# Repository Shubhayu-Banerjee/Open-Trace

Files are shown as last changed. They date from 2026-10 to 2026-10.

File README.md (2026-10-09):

# OpenTrace

OpenTrace is a custom RP2040-based USB logic analyzer designed to capture digital signals from external circuits for inspection on a computer. This repository documents the hardware design completed so far.

OpenTrace v1

## What has been designed

### RP2040 core

- Selected the **Raspberry Pi RP2040** as the main MCU.
- Designed the core around an external **W25Q16JV QSPI flash** (16 Mbit / 2 MB).
- Added the 12 MHz crystal oscillator circuit, using the RP2040 reference topology as the design basis.
- Added local supply decoupling capacitors and the RP2040's 3.3 V / 1.1 V regulator-related connections.
- Tied `TESTEN` low.
- Added a `RUN` reset circuit using a 10 kΩ pull-up to +3V3 and a normally-open momentary switch to GND.

### USB-C interface

- Added a USB-C receptacle for USB 2.0 device connectivity.
- Added separate **5.1 kΩ pull-down resistors from CC1 and CC2 to GND**.
- Combined the receptacle's duplicate USB 2.0 contacts correctly: A6/B6 for D+ and A7/B7 for D−.
- Added a **USBLC6-2SC6** for USB D+/D− ESD protection.
- Added an **AMS1117-3.3** regulator stage to derive 3.3 V from USB VBUS in the current schematic.

### Eight-channel input stage

- Selected the **SN74LVC245A-family octal buffer**, with the current schematic using `SN74LVC245APW`.
- Set `DIR` low for A-to-B signal flow.
- Set active-low `/OE` low to enable the outputs.
- Added a 100 nF bypass capacitor at the buffer's supply.
- Added an eight-signal probe connector (`J2`) and wired its eight signals to buffer inputs A1–A8.
- Wired the corresponding B1–B8 outputs to RP2040 GPIOs **GPIO25 through GPIO18**, respectively:

| Probe / buffer channel | RP2040 GPIO |
|---|---:|
| Channel 1 (A1 → B1) | GPIO18 |
| Channel 2 (A2 → B2) | GPIO19 |
| Channel 3 (A3 → B3) | GPIO20 |
| Channel 4 (A4 → B4) | GPIO21 |
| Channel 5 (A5 → B5) | GPIO22 |
| Channel 6 (A6 → B6) | GPIO23 |
| Channel 7 (A7 → B7) | GPIO24 |
| Channel 8 (A8 → B8) | GPIO25 |

The mapping above records the schematic mapping discussed so far; it must still be checked against the final display/encoder pin assignments.

### Probe-input ESD decision

- Evaluated multiple eight-channel and single-/multi-line ESD protection options, including the SP4065-08ATG, TPD4E05U06, DRTR5V0U4S-7, PESD5V0U1BA, PESD5V0L1BA, NUP4114, and PESD5V0C2BDFZ.
- No probe-side ESD protector was selected as a verified solution. The main blocker was finding a part that was available, had a practical footprint, and had transient/clamping characteristics appropriately evaluated against the SN74LVC245A input limits.
- **The current design decision is to omit the dedicated probe-input ESD array for this revision**, rather than add an unverified component. This leaves the exposed probe inputs without dedicated ESD protection and is a known limitation.
- The USBLC6-2SC6 remains assigned to USB D+/D−, not to the probe inputs.

## Important current design details

| Item | Current design |
|---|---|
| Main MCU | Raspberry Pi RP2040 |
| QSPI flash | W25Q16JV, 16 Mbit / 2 MB |
| Clock | 12 MHz crystal circuit |
| USB | USB-C, USB 2.0 |
| USB ESD | USBLC6-2SC6 on D+/D− |
| USB-to-3.3 V regulator | AMS1117-3.3 candidate |
| Probe buffer | SN74LVC245APW |
| Probe inputs | 8 digital channels |
| Probe-to-GPIO mapping | GPIO25, GPIO24, GPIO23, GPIO22, GPIO21, GPIO20, GPIO19, GPIO18 |
| Probe ESD | Omitted for current revision; not protected by a dedicated ESD array |
| Reset | `RUN` with 10 kΩ pull-up and momentary switch to GND |
| Boot configuration | `TESTEN` tied low; flash/BOOTSEL arrangement needs final verification |

## Decisions and trade-offs made

- Chose **RP2040** rather than a more complex FPGA or another MCU for this revision, prioritizing a feasible custom board and PIO-based deterministic sampling.
- Kept the external QSPI flash and 12 MHz crystal as part of the bare-MCU design.
- Used a USB-C connector with the correct device-side CC pull-down approach.
- Added dedicated ESD protection to the USB data lines.
- Chose the SN74LVC245A-family device as the eight-channel input buffer.
- Deferred probe-input ESD protection because candidate parts were unavailable or could not be validated as a complete protection solution within the current design effort.
- Prioritized getting a coherent, manufacturable first PCB over adding a component whose electrical suitability was uncertain.

## Known limitations / items not yet verified

This repository describes the design work completed so far; it does not claim the PCB has been fabricated or tested.
- The probe inputs have no dedicated ESD array in the current revision. Treat them as unprotected inputs.

## References

- [RP2040 hardware design guide](https://datasheets.raspberrypi.com/rp2040/hardware_design_with_rp2040.pdf)
- [RP2040 documentation portal](https://pip.raspberrypi.com/categories/814-rp2040)
- [Texas Instruments SN74LVC245A](https://www.ti.com/product/SN74LVC245A)
- [ST USBLC6-2SC6](https://www.st.com/en/protections-and-emi-filters/usbllc6-2.html)

## License

No license has been specified yet.

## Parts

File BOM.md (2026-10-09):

# OpenTrace – bill of materials

<!-- Generated by Half Life from project cmv0laarm01us01mcl110xg83. Edits here are overwritten on the next sync. -->
<!-- Generated: 2026-10-09T13:05:42.587Z -->

> [!NOTE]
> This parts list is mirrored from [Half Life](https://halflife.hackclub.com). Editing it here will not change the platform's copy, and the next sync overwrites this file.

| Week | Tier | Parts funding |
| --- | --- | --- |
| Week 1 | Tier 1 | $30.00 |

| Part | What it's for | Qty | Unit | Total | Vendor |
| --- | --- | --- | --- | --- | --- |
| [535-ABM8-272-T3CT-ND](https://www.digikey.in/en/products/detail/abracon-llc/ABM8-272-T3/22472366) | Clock for the RP2040 | 1 | $0.69 | $0.69 | [Digikey](https://www.digikey.in/en/products/detail/abracon-llc/ABM8-272-T3/22472366) |
| [Raspberry PI RP2040 Microcontroller IC](https://robu.in/product/raspberry-pi-rp2040/) | Main controller | 1 | $0.66 | $0.66 | [Robu](https://robu.in/product/raspberry-pi-rp2040/) |
| [TPD4E1U06DBVR](https://robu.in/product/1-month-warranty-448/) | ESD Protection for USB | 2 | $0.52 | $1.04 | [Robu](https://robu.in/product/1-month-warranty-448/) |
| [CC0603JRX7R7BB104](https://robu.in/product/cc0603jrx7r7bb104-yageo-16v-100nf-x7r-%c2%b15-0603-multilayer-ceramic-capacitors-mlcc-smd-smt-rohs/) | 100nF Capacitor for decoupling | 15 | $0.04 | $0.60 | [Robu](https://robu.in/product/cc0603jrx7r7bb104-yageo-16v-100nf-x7r-%c2%b15-0603-multilayer-ceramic-capacitors-mlcc-smd-smt-rohs/) |
| [RC0201FR](https://robu.in/product/rc0201fr-0727rl-yageo-smd-chip-resistor-27-ohm-%c2%b1-1-50-mw-0201-0603-metric-thick-film-general-purpose/) | Resistor for USB (individual cost too little, 28 cost 10.8 INR, 10INR Minimum order, thus entered as 1 unit) | 1 | $0.11 | $0.11 | [Robu](https://robu.in/product/rc0201fr-0727rl-yageo-smd-chip-resistor-27-ohm-%c2%b1-1-50-mw-0201-0603-metric-thick-film-general-purpose/) |
| [RC0603JR](https://robu.in/product/rc0603jr-0710kp-yageo-100mw-thick-film-resistors-%c2%b15-%c2%b1150ppm-%e2%84%83-10k%cf%89-0603-chip-resistor-surface-mount-rohs/) | General resistors | 14 | $0.01 | $0.14 | [Robu](https://robu.in/product/rc0603jr-0710kp-yageo-100mw-thick-film-resistors-%c2%b15-%c2%b1150ppm-%e2%84%83-10k%cf%89-0603-chip-resistor-surface-mount-rohs/) |
| [1k Ohm 1/8W 0603 Surface Mount Chip Resistor](https://robu.in/product/1k-ohm-1-4w-0603-surface-mount-chip-resistor-pack-of-100/) | 1k Ohm general resistor for measurement/protection (due to very low price, the total price of 35 has been kept as 1 unit) | 1 | $0.10 | $0.10 | [Robu](https://robu.in/product/1k-ohm-1-4w-0603-surface-mount-chip-resistor-pack-of-100/) |
| [RT0603DRE075K1L](https://robu.in/product/rt0603dre075k1l-yageo-100mw-thin-film-resistor-75v-%c2%b10-5-%c2%b150ppm-%e2%84%83-5-1k%cf%89-0603-chip-resistor-surface-mount-rohs/) | 5.1Kohm for USB C 5V Request | 6 | $0.02 | $0.12 | [Robu](https://robu.in/product/rt0603dre075k1l-yageo-100mw-thin-film-resistor-75v-%c2%b10-5-%c2%b150ppm-%e2%84%83-5-1k%cf%89-0603-chip-resistor-surface-mount-rohs/) |
| [TYPE-C Receptacle](https://robu.in/product/type-c-31-m-16-hroparts-1-6p-female-type-c-smd-usb/) | programming and power | 1 | $0.47 | $0.47 | [Robu](https://robu.in/product/type-c-31-m-16-hroparts-1-6p-female-type-c-smd-usb/) |
| [W25Q16JWSNIQ](https://robu.in/product/w25q16jwsniq-winbond-elec-16mbit-spi-133mhz-soic-8-nor-flash-rohs/) | 16mbit flash for the RP2040 | 1 | $4.20 | $4.20 | [Robu](https://robu.in/product/w25q16jwsniq-winbond-elec-16mbit-spi-133mhz-soic-8-nor-flash-rohs/) |
| [USBLC6](https://robu.in/product/usblc6-2sc6-ms-msksemi-4-5a-15v-150w-6v-5v-sot-23-6-esd-and-surge-protection-tvs-esd-rohs/) | USB ESD protection | 1 | $0.11 | $0.11 | [Robu](https://robu.in/product/usblc6-2sc6-ms-msksemi-4-5a-15v-150w-6v-5v-sot-23-6-esd-and-surge-protection-tvs-esd-rohs/) |
| [74LVC245AT20](https://robu.in/product/74lvc245at20-13-diodes-incorporated-8-24ma-1-65v3-6v-24ma-1-tssop-20-buffers-drivers-receivers-transceivers-rohs/) | Gives buffering and protection against higher voltages for 8 channels | 1 | $0.26 | $0.26 | [Robu](https://robu.in/product/74lvc245at20-13-diodes-incorporated-8-24ma-1-65v3-6v-24ma-1-tssop-20-buffers-drivers-receivers-transceivers-rohs/) |
| [XL-2012WYC](https://robu.in/product/xl-2012wyc-xinglight-5ma-320mcd-yellow-lens-positive-stick-yellow-130-75mw-2-7v3-1v-0805-led-indication-discrete-rohs/) | Yellow SMD LED (15 * 0.0072USD, single is 0.7INR which is too little to mention individually) | 1 | $0.11 | $0.11 | [robu](https://robu.in/product/xl-2012wyc-xinglight-5ma-320mcd-yellow-lens-positive-stick-yellow-130-75mw-2-7v3-1v-0805-led-indication-discrete-rohs/) |
| [Tact Switch TVDP01- 6.0X6.0mm](https://robu.in/product/tact-switch-tvdp01-6-0x6-0mm/) | Buttons for reset/entering boot mode | 3 | $0.04 | $0.12 | [Robu](https://robu.in/product/tact-switch-tvdp01-6-0x6-0mm/) |
| **Parts subtotal** | — | — | — | **$8.73** | — |
| **Tax & shipping** | — | — | — | **$20.00** | — |
| **Total** | — | — | — | **$28.73** | — |

$1.27 left of the tier's funding.

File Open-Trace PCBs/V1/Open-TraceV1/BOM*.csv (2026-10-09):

Reference | Qty | Value | DNP | Exclude from BOM | Exclude from Board | Footprint | Datasheet
C1,C3,C4,C6,C7,C8,C9,C10,C11,C17,C18 | 11 | 100nF |  |  |  | Capacitor_SMD:C_0603_1608Metric
C5,C12,C15,C16 | 4 | 1 µF |  |  |  | Capacitor_SMD:C_0603_1608Metric
C13,C14 | 2 | 15p |  |  |  | Capacitor_SMD:C_0603_1608Metric
D1 | 1 | LED |  |  |  | LED_SMD:LED_0805_2012Metric
J1 | 1 | USB_C_Receptacle_USB2.0_16P |  |  |  | Connector_USB:USB_C_Receptacle_GCT_USB4105-xx-A_16P_TopMnt_Horizontal | https://www.usb.org/sites/default/files/documents/usb_type-c.zip
J2 | 1 | Conn_01x16_Pin |  |  |  | Connector_PinHeader_2.54mm:PinHeader_1x16_P2.54mm_Vertical
R1,R2,R6 | 3 | 1k |  |  |  | Resistor_SMD:R_0603_1608Metric
R3 | 1 | 10k |  |  |  | Resistor_SMD:R_0603_1608Metric
R4,R5 | 2 | 5.1k |  |  |  | Resistor_SMD:R_0603_1608Metric
SW1 | 1 | Boot_SEL |  |  |  | Button_Switch_THT:SW_PUSH_6mm
SW2 | 1 | RUN |  |  |  | Button_Switch_THT:SW_PUSH_6mm
U1 | 1 | RP2040 |  |  |  | Package_DFN_QFN:QFN-56-1EP_7x7mm_P0.4mm_EP3.2x3.2mm | https://datasheets.raspberrypi.com/rp2040/rp2040-datasheet.pdf
U2 | 1 | SN74LVC245APW |  |  |  | Package_SO:TSSOP-20_4.4x6.5mm_P0.65mm | https://www.ti.com/lit/ds/scas218x/scas218x.pdf
U3 | 1 | USBLC6-2SC6 |  |  |  | Package_TO_SOT_SMD:SOT-23-6 | https://www.st.com/resource/en/datasheet/usblc6-2.pdf
U4 | 1 | W25Q16JVSS |  |  |  | Package_SO:SOIC-8_5.3x5.3mm_P1.27mm | https://www.winbond.com/hq/support/documentation/levelOne.jsp?__locale=en&DocNo=DA00-W25Q16JV.1
U5 | 1 | AMS1117-3.3 |  |  |  | Package_TO_SOT_SMD:SOT-223-3_TabPin2 | http://www.advanced-monolithic.com/pdf/ds1117.pdf
Y1 | 1 | Crystal_GND24 |  |  |  | Crystal:Crystal_SMD_3225-4Pin_3.2x2.5mm

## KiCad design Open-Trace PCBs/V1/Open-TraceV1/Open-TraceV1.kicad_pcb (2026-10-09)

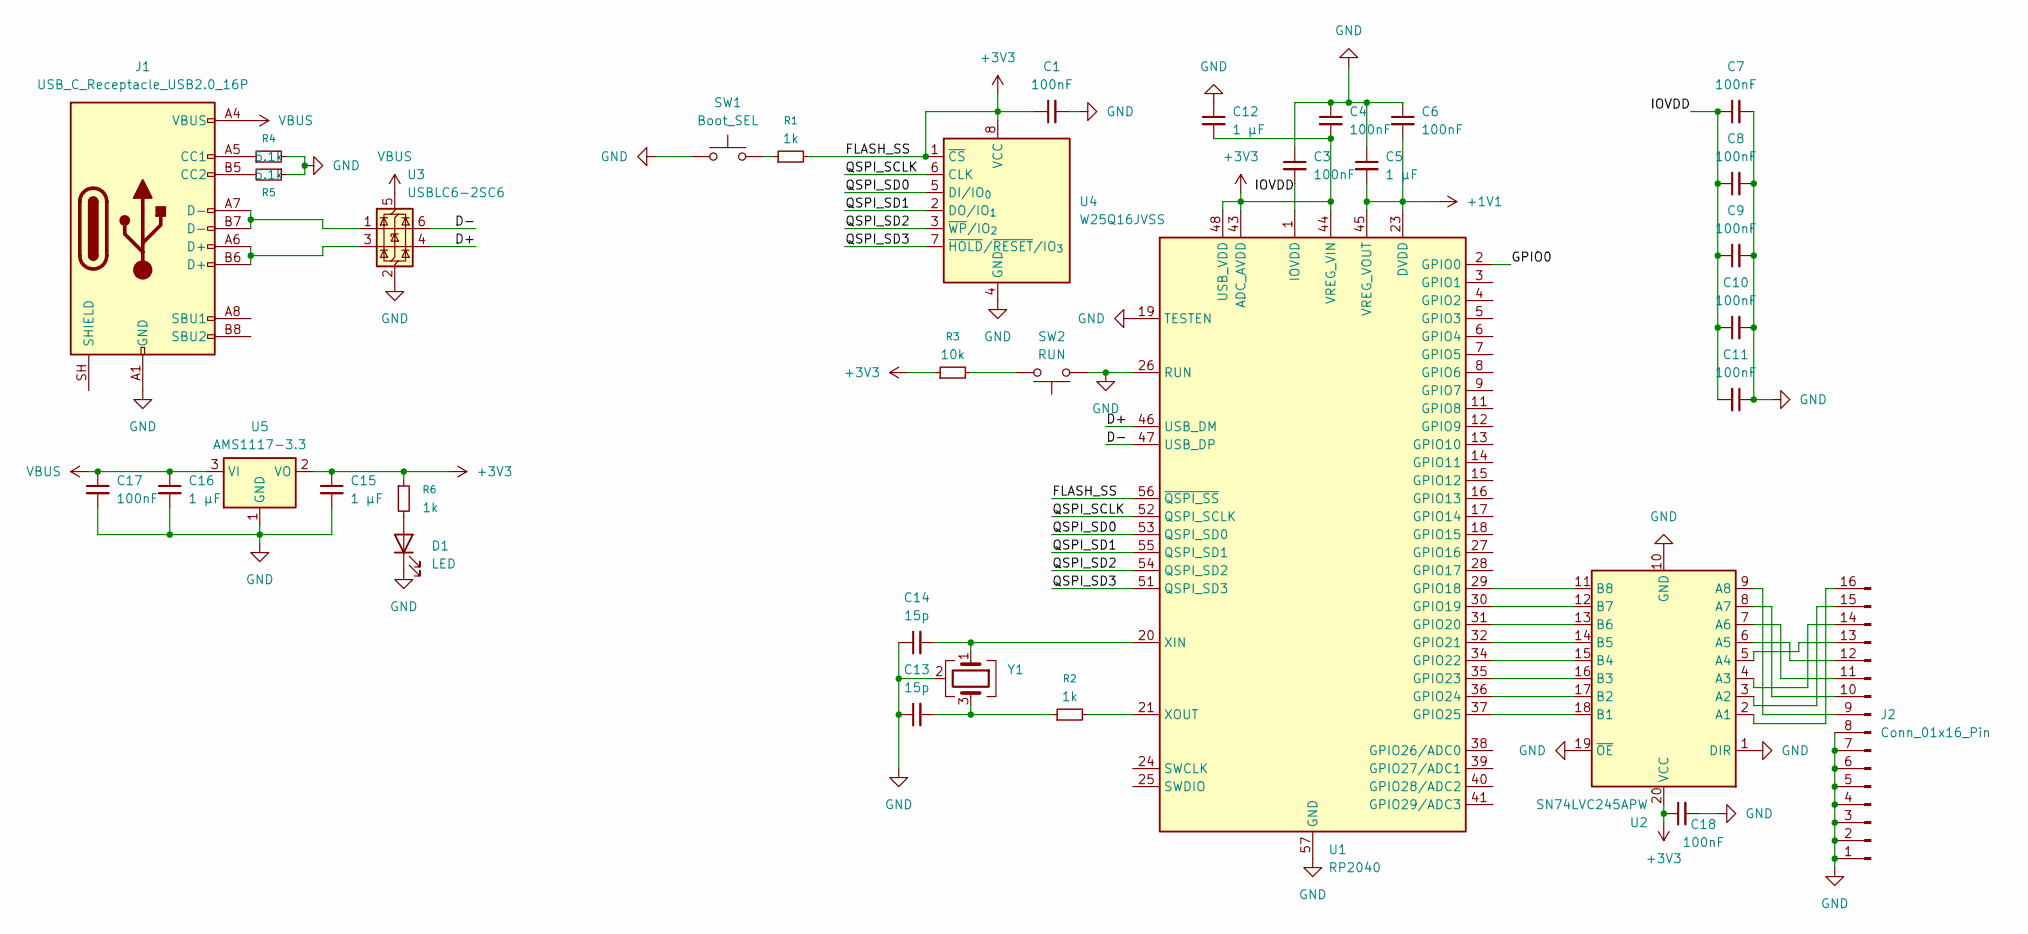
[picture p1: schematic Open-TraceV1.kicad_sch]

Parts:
C1, C3, C4, C6, C7, C8, C9, C10, C11, C17, C18: 100nF; C_0603_1608Metric
C5, C12, C15, C16: 1 µF; C_0603_1608Metric
C13, C14: 15p; C_0603_1608Metric
D1: LED; LED_0805_2012Metric
J1: USB_C_Receptacle_USB2.0_16P; USB_C_Receptacle_GCT_USB4105-xx-A_16P_TopMnt_Horizontal
J2: Conn_01x16_Pin; PinHeader_1x16_P2.54mm_Vertical
R1, R2, R6: 1k; R_0603_1608Metric
R3: 10k; R_0603_1608Metric
R4, R5: 5.1k; R_0603_1608Metric
SW1: Boot_SEL; SW_PUSH_6mm
SW2: RUN; SW_PUSH_6mm
U1: RP2040; QFN-56-1EP_7x7mm_P0.4mm_EP3.2x3.2mm
U2: SN74LVC245APW; TSSOP-20_4.4x6.5mm_P0.65mm
U3: USBLC6-2SC6; SOT-23-6
U4: W25Q16JVSS; SOIC-8_5.3x5.3mm_P1.27mm
U5: AMS1117-3.3; SOT-223-3_TabPin2
Y1: Crystal_GND24; Crystal_SMD_3225-4Pin_3.2x2.5mm

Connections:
+1V1: C5.2, C6.2, U1.23 (DVDD), U1.45 (VREG_VOUT), U1.50 (DVDD)
+3V3: C1.1, C4.2, C12.2, C15.1, C18.1, R1.2, R3.1, R6.1, U1.43 (ADC_AVDD), U1.44 (VREG_VIN), U1.48 (USB_VDD), U1.56 (~QSPI_SS), U2.20 (VCC), U4.1 (~CS), U4.8 (VCC), U5.2 (VO)
/D+: U1.46 (USB_DM), U3.4 (I/O2)
/D-: U1.47 (USB_DP), U3.6 (I/O1)
/GPIO0: U1.2 (GPIO0)
/IOVDD: C3.2, C7.1, C8.1, C9.1, C10.1, C11.2, U1.1 (IOVDD), U1.10 (IOVDD), U1.22 (IOVDD), U1.33 (IOVDD), U1.42 (IOVDD), U1.49 (IOVDD)
/QSPI_SCLK: U1.52 (QSPI_SCLK), U4.6 (CLK)
/QSPI_SD0: U1.53 (QSPI_SD0), U4.5 (DI/IO_{0})
/QSPI_SD1: U1.55 (QSPI_SD1), U4.2 (DO/IO_{1})
/QSPI_SD2: U1.54 (QSPI_SD2), U4.3 (~WP/IO_{2})
/QSPI_SD3: U1.51 (QSPI_SD3), U4.7 (~HOLD/~RESET/IO_{3})
GND: C1.2, C3.1, C4.1, C5.1, C6.1, C7.2, C8.2, C9.2, C10.2, C11.1, C12.1, C13.1, C14.1, C15.2, C16.2, C17.2, C18.2, D1.1 (K), J1.A1 (GND), J1.A12 (GND), J1.B1 (GND), J1.B12 (GND), J2.1, J2.2, J2.3, J2.4, J2.5, J2.6, J2.7, J2.8, R4.2, R5.1, SW1.1, SW2.1, U1.19 (TESTEN), U1.26 (RUN), U1.57 (GND), U2.1 (DIR), U2.10 (GND), U2.19 (~OE), U3.2 (GND), U4.4 (GND), U5.1 (GND), Y1.2 (G), Y1.4 (G)
unnamed: C13.2, R2.1, Y1.3
unnamed: D1.2 (A), R6.2
unnamed: J1.A5 (CC1), R4.1
unnamed: J1.B5 (CC2), R5.2
unnamed: J1.A6 (D+), J1.B6 (D+), U3.3 (I/O2)
unnamed: J1.A7 (D-), J1.B7 (D-), U3.1 (I/O1)
unnamed: J2.9, U2.9 (A8)
unnamed: J2.10, U2.8 (A7)
unnamed: J2.11, U2.7 (A6)
unnamed: J2.12, U2.6 (A5)
unnamed: J2.13, U2.5 (A4)
unnamed: J2.14, U2.4 (A3)
unnamed: J2.15, U2.3 (A2)
unnamed: J2.16, U2.2 (A1)
unnamed: R1.1, SW1.2
unnamed: R3.2, SW2.2
unnamed: U1.29 (GPIO18), U2.11 (B8)
unnamed: U1.30 (GPIO19), U2.12 (B7)
unnamed: U1.31 (GPIO20), U2.13 (B6)
unnamed: U1.32 (GPIO21), U2.14 (B5)
unnamed: U1.34 (GPIO22), U2.15 (B4)
unnamed: U1.35 (GPIO23), U2.16 (B3)
unnamed: U1.36 (GPIO24), U2.17 (B2)
unnamed: U1.37 (GPIO25), U2.18 (B1)
unnamed: C14.2, U1.20 (XIN), Y1.1
unnamed: R2.2, U1.21 (XOUT)
VBUS: C16.1, C17.1, J1.A4 (VBUS), J1.A9 (VBUS), J1.B4 (VBUS), J1.B9 (VBUS), U3.5 (VBUS), U5.3 (VI)

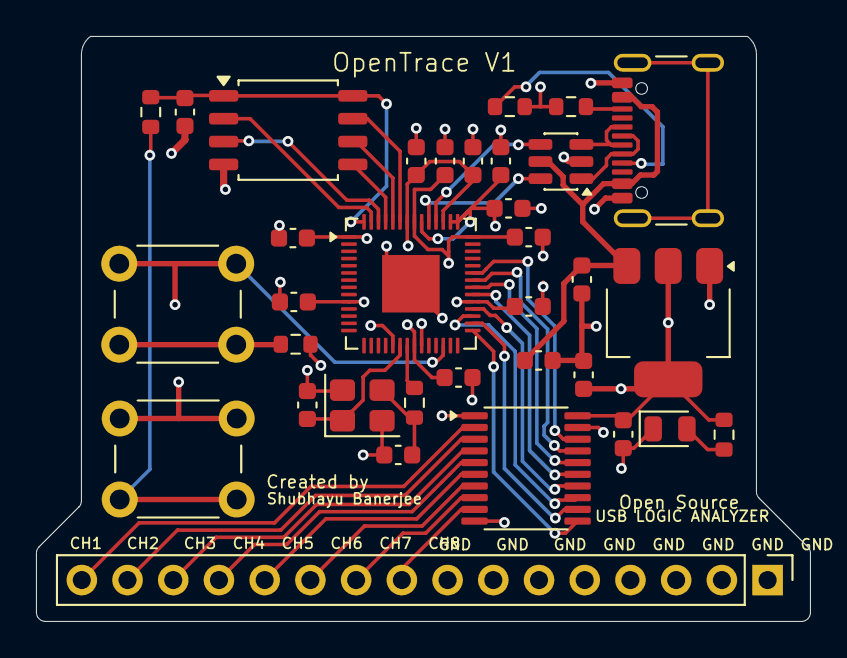
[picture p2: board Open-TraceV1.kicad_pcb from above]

Board: 4 copper layers, 43.0 x 32.5 mm, 34 parts (0 on the bottom side), 38 nets.

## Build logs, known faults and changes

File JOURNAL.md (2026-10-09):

# OpenTrace – devlog

<!-- Generated by Half Life from project cmv0laarm01us01mcl110xg83. Edits here are overwritten on the next sync. -->
<!-- Generated: 2026-10-09T14:49:38.285Z -->

> [!NOTE]
> This devlog is mirrored from [Half Life](https://halflife.hackclub.com). Editing it here will not change the platform's copy, and the next sync overwrites this file.

> 8-channel USB logic analyzer! Never had a logic analyzer, so this is the perfect opportunity!

| Week | Tier | Hours logged | Entries |
| --- | --- | --- | --- |
| Week 1 | Tier 1 | 10.5h | 7 |

## Contents

1. [2026-10-09 – After evaluating the initial design, I chose to move beyond a basic RP2040-based analyzer and upgrade to the RP2350A, providing additional SRAM and more programmable I/O resources for the capture syst](#2026-10-09-after-evaluating-the-initial-design-i-chose-to-mo)
2. [2026-10-09 – Here I setup wired the external 16bit Flash. It made me heavily contemplate just using an esp32 class chip since I have a lot of experience with those, but I think I'm going to fully stick to the RP23](#2026-10-09-here-i-setup-wired-the-external-16bit-flash-it-ma)
3. [2026-10-09 – I worked on the internal regulator components. I've always been scared of using inductors due to their magnetic properties and how they can interfere with other components, but it's going to be a nece](#2026-10-09-i-worked-on-the-internal-regulator-components-ive)
4. [2026-10-09 – Routed USB 2.0; Buttons for reset and boot selection, and the AMS1117 for 5v from usb to 3.3v for the board. I've decided to make it a 4 layer board. Simply way tooo many ground connections to realist](#2026-10-09-routed-usb-20-buttons-for-reset-and-boot-selectio)
5. [2026-10-09 – Connected up the buffer, went down a rabbit hole of ESD diodes only to ultimately not use any... not ideal.. but don't got any other option due to part availability sadly. Anyways the board is semi-of](#2026-10-09-connected-up-the-buffer-went-down-a-rabbit-hole-o)
6. [2026-10-09 – And OpenTrace v1 is finally done! Such a speed run haha. Well praying it works! Finished up the silkscreen, added the logo and my name, labelled the channels too. Looking great! Can't wait to get this](#2026-10-09-and-opentrace-v1-is-finally-done-such-a-speed-run)
7. [2026-10-09 – Built the .md and initial v0 firmware for OpenTrace. Obviously since I don't have the board, I can't test it, but I'll have to wait until the final board comes to be completely sure. Really excited an](#2026-10-09-built-the-md-and-initial-v0-firmware-for-opentrac)

## Design

### 2026-10-09 – After evaluating the initial design, I chose to move beyond a basic RP2040-based analyzer and upgrade to the RP2350A, providing additional SRAM and more programmable I/O resources for the capture syst

**2h**

After evaluating the initial design, I chose to move beyond a basic RP2040-based analyzer and upgrade to the RP2350A, providing additional SRAM and more programmable I/O resources for the capture system. The current design targets eight digital input channels compatible with 3.3 V and 5 V logic signals, with the goal of capturing digital activity and transferring recorded traces to a computer over USB.

To make the instrument more usable, I expanded the design to include a TFT display and three rotary encoders. These will eventually provide a local interface for monitoring capture status, navigating settings, selecting channels, and configuring capture parameters. The computer will remain the primary interface for detailed waveform analysis.

I began developing the schematic in KiCad and added the main components: the RP2350A microcontroller, USB-C receptacle, SN74LVC245A eight-channel buffer, USBLC6-2SC6 USB ESD protection device, external W25Q16 flash memory, and a 12 MHz crystal. I also started selecting the associated passive components and connectors from Robu.in while keeping the overall project within the $65 Tier 2 budget.

Input protection became an important part of the design. I selected the SN74LVC245A as a candidate for buffering the eight input channels and investigated suitable ESD protection. After comparing available components, I shortlisted two TPD4E1U06 devices to protect all eight exposed inputs. For USB protection, I checked the USBLC6-2SC6 datasheet and began planning its placement and connections near the USB-C connector.
Oh oh and  I also learned to distinguish between passive crystals and active clock oscillators, identifying a 12 MHz, 10 ppm SMD crystal as a more promising candidate, over accidentally choosing a 27.12 MHz crystal randomly 😭.





### 2026-10-09 – Here I setup wired the external 16bit Flash. It made me heavily contemplate just using an esp32 class chip since I have a lot of experience with those, but I think I'm going to fully stick to the RP23

**1.5h**

Here I setup wired the external 16bit Flash. It made me heavily contemplate just using an esp32 class chip since I have a lot of experience with those, but I think I'm going to fully stick to the RP2350A due to it having PIOs which will be useful for proper timing.



I'll be working on the internal regulator next with the help of the official hardware design guide.



### 2026-10-09 – I worked on the internal regulator components. I've always been scared of using inductors due to their magnetic properties and how they can interfere with other components, but it's going to be a nece

**2.5h**

I worked on the internal regulator components. I've always been scared of using inductors due to their magnetic properties and how they can interfere with other components, but it's going to be a necessary part. Again... another pain point that made me want to shift to an ESP32... but finger's crossed cus' PIOs!

Anddddd never mind 💀
I couldn't find the required abracon inductor.... so I've switched over to the RP2040. I do get about only half the SRAM but it'll have to do.

I also configured the clock and it was a NIGHTMARE FINDING THE RIGHT PART IN STOCK!🙏😭.







### 2026-10-09 – Routed USB 2.0; Buttons for reset and boot selection, and the AMS1117 for 5v from usb to 3.3v for the board. I've decided to make it a 4 layer board. Simply way tooo many ground connections to realist

**1.5h**

Routed USB 2.0; Buttons for reset and boot selection, and the AMS1117 for 5v from usb to 3.3v for the board. I've decided to make it a 4 layer board. Simply way tooo many ground connections to realistically route them all through  a 2 layer board. Gonna work on the probe part next!





### 2026-10-09 – Connected up the buffer, went down a rabbit hole of ESD diodes only to ultimately not use any... not ideal.. but don't got any other option due to part availability sadly. Anyways the board is semi-of

**1.5h**

Connected up the buffer, went down a rabbit hole of ESD diodes only to ultimately not use any... not ideal.. but don't got any other option due to part availability sadly. Anyways the board is semi-officially done! Only thing that is left now is for the silkscreen (;





### 2026-10-09 – And OpenTrace v1 is finally done! Such a speed run haha. Well praying it works! Finished up the silkscreen, added the logo and my name, labelled the channels too. Looking great! Can't wait to get this

**0.5h**

And OpenTrace v1 is finally done! Such a speed run haha. Well praying it works! Finished up the silkscreen, added the logo and my name, labelled the channels too. Looking great! Can't wait to get this thing built and test it out!





### 2026-10-09 – Built the .md and initial v0 firmware for OpenTrace. Obviously since I don't have the board, I can't test it, but I'll have to wait until the final board comes to be completely sure. Really excited an

**1h**

Built the .md and initial v0 firmware for OpenTrace. Obviously since I don't have the board, I can't test it, but I'll have to wait until the final board comes to be completely sure. Really excited and looking forward to week 6!!!!





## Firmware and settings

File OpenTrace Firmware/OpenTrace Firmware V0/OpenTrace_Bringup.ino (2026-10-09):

/*
  OpenTrace — temporary bring-up firmware
  Target: Raspberry Pi RP2040
  Framework: Arduino-Pico core (Raspberry Pi Pico / RP2040)

  Purpose:
    - Confirm the RP2040 boots and enumerates as USB serial.
    - Confirm the eight SN74LVC245A output channels reach the expected GPIOs.
    - Print a channel bitmask when the input state changes.

  IMPORTANT:
    This is a low-speed GPIO polling test, NOT the final high-speed logic analyzer.
    It does not use PIO/DMA and cannot guarantee narrow-pulse capture.
*/

#include <Arduino.h>

static constexpr uint32_t SERIAL_BAUD = 115200;
static constexpr uint32_t REPORT_INTERVAL_MS = 100;

// Based on the current schematic mapping:
// CH1=A1->B1 -> GPIO25, CH2 -> GPIO24, ... CH8 -> GPIO18.
static constexpr uint8_t CHANNEL_PINS[8] = {
  25, 24, 23, 22, 21, 20, 19, 18
};

uint8_t readChannels() {
  uint8_t state = 0;
  for (uint8_t ch = 0; ch < 8; ++ch) {
    if (digitalRead(CHANNEL_PINS[ch]) == HIGH) {
      state |= (uint8_t)(1u << ch);
    }
  }
  return state;
}

void printState(uint8_t state) {
  Serial.print(F("CH1..CH8 = "));
  for (int8_t ch = 7; ch >= 0; --ch) {
    Serial.print((state >> ch) & 1u);
  }

  Serial.print(F("  HEX=0x"));
  if (state < 0x10) Serial.print('0');
  Serial.println(state, HEX);
}

void setup() {
  // Use INPUT: the SN74LVC245A actively drives these GPIOs.
  for (uint8_t ch = 0; ch < 8; ++ch) {
    pinMode(CHANNEL_PINS[ch], INPUT);
  }

  Serial.begin(SERIAL_BAUD);

  // Don't block indefinitely if no serial terminal is open.
  const uint32_t start = millis();
  while (!Serial && (millis() - start < 3000)) {
    delay(10);
  }

  Serial.println();
  Serial.println(F("OpenTrace temporary bring-up firmware"));
  Serial.println(F("RP2040 USB serial: OK"));
  Serial.println(F("8-channel GPIO polling test"));
  Serial.println(F("Mapping: CH1=GPIO25, CH2=GPIO24, CH3=GPIO23, CH4=GPIO22,"));
  Serial.println(F("         CH5=GPIO21, CH6=GPIO20, CH7=GPIO19, CH8=GPIO18"));
  Serial.println(F("Send 's' to print the current state."));
  Serial.println(F("NOTE: slow polling only; not final logic-analyzer capture."));
  printState(readChannels());
}

void loop() {
  static uint8_t previousState = 0xFF;
  static uint32_t lastReport = 0;

  const uint32_t now = millis();
  const uint8_t state = readChannels();

  // Print immediately whenever any channel changes.
  if (state != previousState) {
    Serial.print(millis());
    Serial.print(F(" ms  "));
    printState(state);
    previousState = state;
    lastReport = now;
  }

  // Allow a terminal to request a fresh state.
  while (Serial.available() > 0) {
    const char command = (char)Serial.read();
    if (command == 's' || command == 'S') {
      Serial.print(millis());
      Serial.print(F(" ms  "));
      printState(state);
    }
  }

  // Periodic heartbeat so the terminal shows the firmware is alive.
  if (now - lastReport >= REPORT_INTERVAL_MS) {
    Serial.print(millis());
    Serial.print(F(" ms  "));
    printState(state);
    lastReport = now;
  }
}

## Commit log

2026-10-09 Revise README for OpenTrace project details
    Updated the README to reflect the current design status and details of the OpenTrace RP2040-based USB logic analyzer project, including hardware specifications and limitations.
2026-10-09 Update BOM.csv file in Open-TraceV1 directory
    [BOM*.csv]
2026-10-13 Add BOM section to README
    Added Bill of Materials (BOM) section with component details.
2026-10-13 Refactor BOM section to Markdown format
    Updated BOM table format to Markdown for better readability.
